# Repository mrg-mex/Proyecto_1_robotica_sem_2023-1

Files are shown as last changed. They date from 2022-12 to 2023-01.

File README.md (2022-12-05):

# Proyecto_1_robotica_sem_2023-1
## Implementación de un robot 5R, con motores de modelismo

## Participantes
- M.I. Erik Peña Medina (responsable)
- Castañeda López Josué Ángel (participante) 
- López Ortiz Alan (participante)
- Nava Dominguez José Carlos (participante)

## Objetivo

Implementar un robot un robot serial de cinco grados de libertad que conforme un banco de pruebas para prácticas de robótica, mediante el desarrollo de una interfase de control.

## Metas
- Desarrollar el modelo cinemático del robot serial de 5 grados de libertad en función del modelo de CAD que representa el robot físico. 
- Desarrollar el modelo URDF del robot para su implementación en Matlab y ROS2.
- Desarrollar una interfase de control de robot mediante una Raspberry Pi 4 y un controlador empleando Pca9685, empleando la librería de Adifrut en Python y ROS2.

## Productos
- Un repositorio con los archivos desarrollados durante el proyecto.
- Una interfase de control que permita programación de tareas mediante la planeación de tareas en el espacio de las juntas del robot.
- Completar el banco de pruebas físicos del robot de tal manera que pueda se implementada una interfaz de control en Matlab y ROS2.*

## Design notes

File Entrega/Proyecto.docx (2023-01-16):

Nombres: Castañeda López Josué Ángel, López Ortiz Alan & Nava Domínguez José Carlos Grupo: 01 Fecha: 13/01/2023

Proyecto: Implementación de un robot 5R, con motores de modelismo.

Objetivo

Implementar un robot serial de cinco grados de libertad que conforme un banco de pruebas para prácticas de robótica, mediante el desarrollo de una interfase de control.

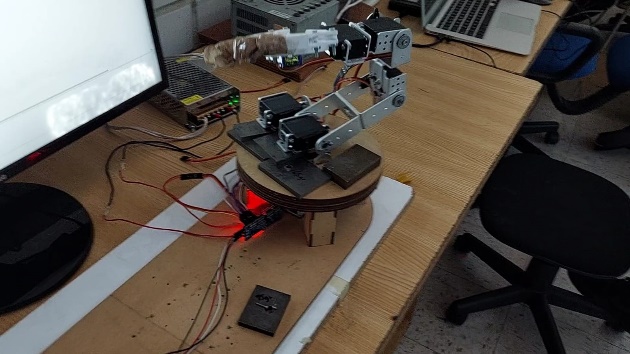
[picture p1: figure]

Figura 1: Robot 5R.

Configuración e instalación

Se nos proporcionó el robot de la figura 1, una raspberry Pi 4 computer model B, una pantalla y un mouse con teclado para poder realizar las actividades previstas del proyecto y el módulo PCA9685.

El profesor nos hizo el favor de instalar la imagen que contenía el sistema operativo Raspbian.

Como se decidió trabajar en Python necesitamos agregar soporte SMBus que incluye I2C. Con ayuda del siguiente código ingresado directo a la terminal se instaló el SMBus:

sudo apt-get install python-smbus<font></font>

sudo apt-get install i2c-tools

Con respecto a Python, utilizamos Thonny que ya venía instalado en el Raspbian.

Se conecto de primera instancia un Servomotor del robot modelo MG995 para empezar a hacer pruebas. Se conectó la Rasberry con el PCA9685 como se muestra en la siguiente figura:

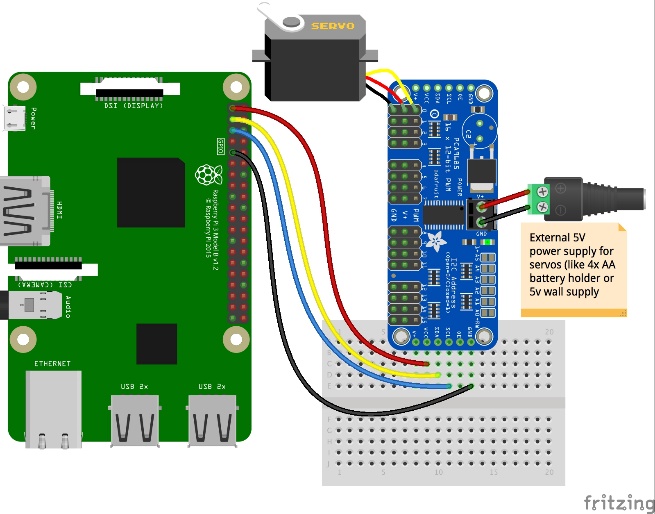
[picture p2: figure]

Figura 2: Conexión de un servomotor.

El PCA9685 funciona con el suministro de 3.3V por lo que debe de conectarse tal cual se ve en la imagen, esto para evitar estropear la RasPI.

Necesitamos instalar la librería Adafruit_Blinka para poder controlar los servomotores con Python, para esto se necesita ejecutar desde la terminal el siguiente comando:

sudo pip3 install adafruit-circuitpython-servokit

En este punto empezamos a realizar la primera prueba que puede verse en el siguiente código:

#Prueba 1 del servomotor 0 ubicado en el canal 0 con continuacion del servo 1 ubicado en el canal 1

import time

from adafruit_servokit import Servokit #en estas dos lineas importamos las librerias

#establecer canales respecto a la cantidad de canales del servo

#8 para servo FeatherWing de 8x12 bit PWM, 16 para Sheld/Hat/Bonnet

kit = Servokit(channels=16) #nuestro caso fue de 16

kit.servo[0].angle=180 #mover el servo conectado al canal 0 a 180 grados

kit.continuous_servo[1].throttle=1 #iniciar el servo de rotación continua conectado al canal 1 a toda velocidad hacia adelante

time.sleep(1) #tiempo de espera

kit.continuous_servo[1].throttle=-1 #iniciar el servo de rotación continua conectado al canal 1 a toda velocidad hacia atras

time.sleep(1)

kit.servo[0].angle=0 #mover el servo conectado al canal 0 a 0 grados

kit.continuous_servo[1].throttle=0 #detiene el servo de rotación continua conectado al canal 1

Una vez verificamos el funcionamiento del código, proseguimos a conectar todos los servos como se puede ver en la figura 3

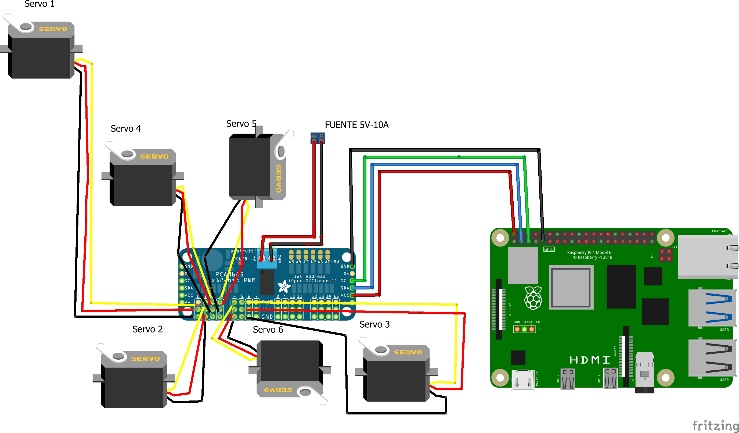
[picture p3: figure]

Figura 3: Conexión de los servomotores.

Continuamos con la prueba dos en la que movimos en conjunto todos los servos, también se hizo la prueba de moverlo uno a uno, pero finalmente se dejó como en el siguiente código:

#Prueba 2 conexion de todos los servomotores

import time

from adafruit_servokit import Servokit #en estas dos lineas importamos las librerias

#establecer canales respecto a la cantidad de canales del servo

#8 para servo FeatherWing de 8x12 bit PWM, 16 para Sheld/Hat/Bonnet

kit = Servokit(channels=16)

#servo1

kit.servo[0].angle=0 #mover el servo conectado al canal 0 a 0 grados

kit.continuous_servo[1].throttle=1 #iniciar el servo de rotación continua conectado al canal 1 a toda velocidad hacia adelante

time.sleep(1) #tiempo de espera

kit.continuous_servo[1].throttle=-1 #iniciar el servo de rotación continua conectado al canal 1 a toda velocidad hacia atras

time.sleep(1)

kit.servo[0].angle=0 #mover el servo conectado al canal 0 a 0 grados

kit.continuous_servo[1].throttle=0 #detiene el servo de rotación continua conectado al canal 1

#servo2

kit.servo[2].angle=0 #mover el servo conectado al canal 2 a 0 grados

kit.continuous_servo[1].throttle=1 #iniciar el servo de rotación continua conectado al canal 1 a toda velocidad hacia adelante

time.sleep(1) #tiempo de espera

kit.continuous_servo[1].throttle=-1 #iniciar el servo de rotación continua conectado al canal 1 a toda velocidad hacia atras

time.sleep(1)

kit.servo[2].angle=0 #mover el servo conectado al canal 2 a 0 grados

kit.continuous_servo[1].throttle=0 #detiene el servo de rotación continua conectado al canal 1

#servo4

kit.servo[3].angle=90 #mover el servo conectado al canal 3 a 90 grados

kit.continuous_servo[2].throttle=1 #iniciar el servo de rotación continua conectado al canal 2 a toda velocidad hacia adelante

time.sleep(1) #tiempo de espera

kit.continuous_servo[2].throttle=-1 #iniciar el servo de rotación continua conectado al canal 2 a toda velocidad hacia atras

time.sleep(1)

kit.servo[3].angle=0 #mover el servo conectado al canal 3 a 0 grados

kit.continuous_servo[2].throttle=0 #detiene el servo de rotación continua conectado al canal 2

#servo5

kit.servo[4].angle=90 #mover el servo conectado al canal 4 a 90 grados

kit.continuous_servo[3].throttle=1 #iniciar el servo de rotación continua conectado al canal 3 a toda velocidad hacia adelante

time.sleep(1) #tiempo de espera

kit.continuous_servo[3].throttle=-1 #iniciar el servo de rotación continua conectado al canal 3 a toda velocidad hacia atras

time.sleep(1)

kit.servo[4].angle=0 #mover el servo conectado al canal 4 a 0 grados

kit.continuous_servo[3].throttle=0 #detiene el servo de rotación continua conectado al canal 3

#servo6

kit.servo[5].angle=90 #mover el servo conectado al canal 5 a 90 grados

kit.continuous_servo[4].throttle=1 #iniciar el servo de rotación continua conectado al canal 4 a toda velocidad hacia adelante

time.sleep(1) #tiempo de espera

kit.continuous_servo[4].throttle=-1 #iniciar el servo de rotación continua conectado al canal 4 a toda velocidad hacia atras

time.sleep(1)

kit.servo[5].angle=0 #mover el servo conectado al canal 5 a 0 grados

kit.continuous_servo[4].throttle=0 #detiene el servo de rotación continua conectado al canal 4

Una vez verificamos el funcionamiento de los motores, nos percatamos que el robot estaba mal armado y la posición 0 de nuestros motores no correspondía con la posición 0 de las piezas, por lo que se prosiguió a corregir este error.

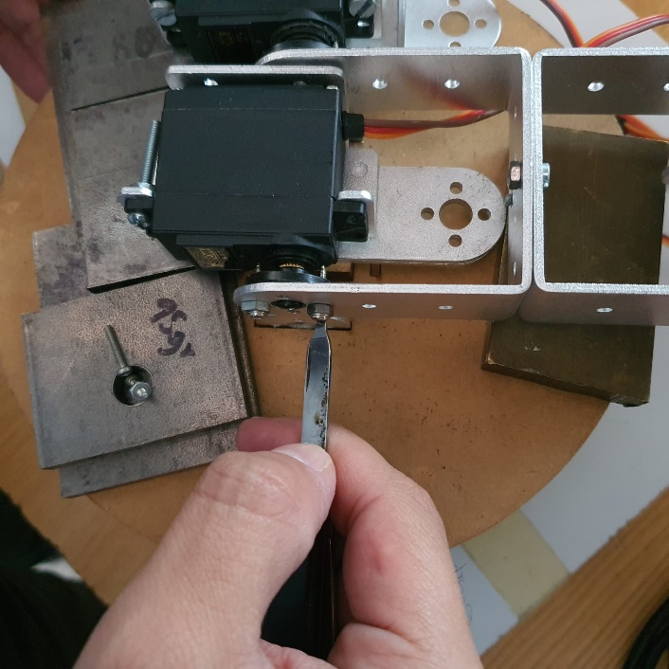
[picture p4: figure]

Figura 4: Corrección de las piezas del motor.

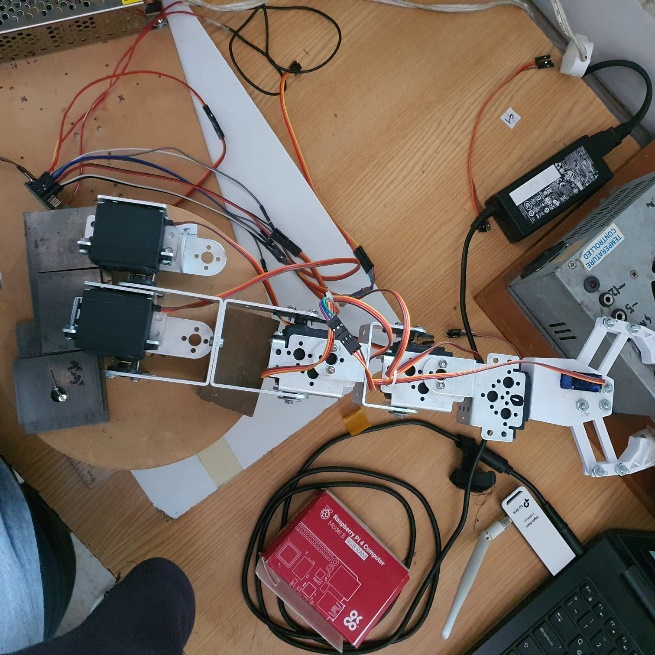
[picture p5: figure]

Figura 5: Robot en posición 0.

Continuamos con la prueba tres como en el siguiente código:

#Prueba 3 conexion de todos los servomotores sin retrocesos

from time import *

from adafruit_servokit import Servokit #en estas dos lineas importamos

#establecer canales respecto a la cantidad de canales del servo

#8 para servo FeatherWing de 8x12 bit PWM, 16 pata Sheld/Hat/Bonnet

kit = Servokit(channels=16)

#Se colocan los angulos iniciales de todos los servos

kit.servo[0].angle=0 #servo conectado al canal 0 a 0 grados

kit.servo[1].angle=0 #servo conectado al canal 1 a 0 grados

kit.servo[2].angle=0 #servo conectado al canal 2 a 0 grados

kit.servo[3].angle=0 #servo conectado al canal 3 a 0 grados

kit.servo[4].angle=0 #servo conectado al canal 4 a 0 grados

def servo1():

kit.servo[0].angle=0 #servo1 conectado en el canal 0 se posiciona a 0 grados

def servo2():

kit.servo[1].angle=90 #servo2 conectado en el canal 1 se posiciona a 90 grados

def servo4():

kit.servo[2].angle=0 #servo4 conectado en el canal 2 se posiciona a 0 grados

def servo5():

kit.servo[3].angle=0 #servo5 conectado en el canal 3 se posiciona a 0 grados

def servo6():

kit.servo[4].angle=0 #servo6 conectado en el canal 4 se posiciona a 0 grados

#Se crea un bucle

while True:

servo1()

sleep(0.5)

servo2()

sleep(0.5)

servo4()

sleep(0.5)

servo5()

sleep(0.5)

servo6()

sleep(0.5)

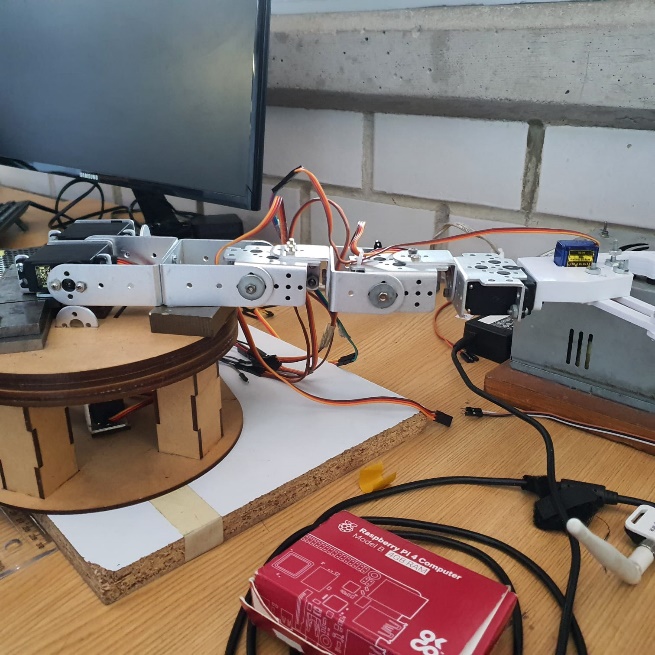
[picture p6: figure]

Figura 5: Robot en ejecución Prueba3.

Con la prueba 3 nos dimos cuenta de que la fuerza en el servomotor 2 no era suficiente para poner el robot en posición de 90°, algo que ya suponíamos porque las dimensiones y masa del robot suponen un para muy grande. Por este motivo y dando solución a este problema decidimos acoplar el motor 3 en paralelo al motor 2 y de esta forma poder soportar el par generado por el robot. Un problema que tuvimos con esto fue de nuevo ajustar a cero el servomotor 3 y, sobre todo, acoplarlo con el servomotor 2.

Después de volver a calibrar los motores se conecto el servomotor 3 como se puede apreciar en la figura 6 y se ejecutó el siguiente código:

#Prueba Final robot levantado a 90 grados

from time import *

from adafruit_servokit import Servokit #en estas dos lineas importamos

#establecer canales respecto a la cantidad de canales del servo

#8 para servo FeatherWing de 8x12 bit PWM, 16 pata Sheld/Hat/Bonnet

kit = Servokit(channels=16)

#Se colocan los angulos iniciales de todos los servos

kit.servo[0].angle=0 #servo conectado al canal 0 a 0 grados

kit.servo[1].angle=0 #servo conectado al canal 1 a 0 grados

kit.servo[2].angle=0 #servo conectado al canal 2 a 0 grados

kit.servo[3].angle=0 #servo conectado al canal 3 a 0 grados

kit.servo[4].angle=0 #servo conectado al canal 4 a 0 grados

kit.servo[5].angle=0 #servo conectado al canal 5 a 0 grados

def servo1():

kit.servo[0].angle=0 #servo1 conectado en el canal 0 se posiciona a 0 grados

def servo2():

kit.servo[1].angle=90 #servo2 conectado en el canal 1 se posiciona a 90 grados

def servo3():

kit.servo[5].angle=90 #servo5 conectado en el canal 1 se posiciona a 90 grados

def servo4():

kit.servo[2].angle=0 #servo4 conectado en el canal 2 se posiciona a 0 grados

def servo5():

kit.servo[3].angle=0 #servo5 conectado en el canal 3 se posiciona a 0 grados

def servo6():

kit.servo[4].angle=0 #servo6 conectado en el canal 4 se posiciona a 0 grados

#Se crea un bucle

while True:

servo1()

sleep(0.5)

servo2()

sleep(0.5)

servo3()

sleep(0.5)

servo4()

sleep(0.5)

servo5()

sleep(0.5)

servo6()

sleep(0.5)

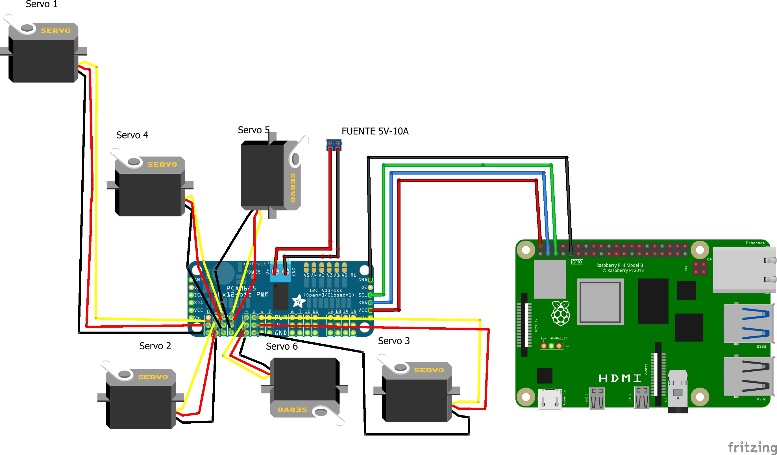
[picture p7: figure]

Figura 6: Conexión de los servomotores completa.

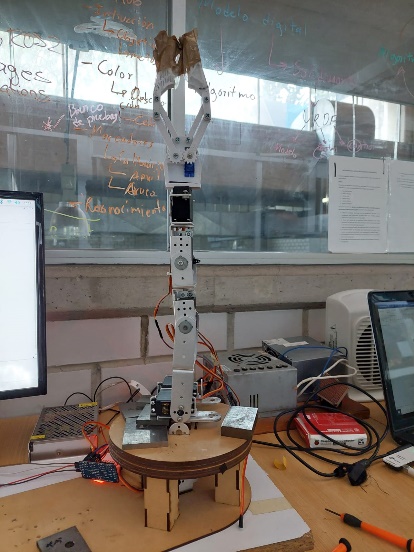
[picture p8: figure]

Figura 7:Robot levantado a 90°.

Referencias

Universidad Nacional Autónoma de México Facultad de Ingeniería Robótica

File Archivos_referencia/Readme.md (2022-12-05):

# Drive de referencia

https://drive.google.com/drive/folders/1qxG93VuVd_5UFDO-JclJPosKGj1U45Qc

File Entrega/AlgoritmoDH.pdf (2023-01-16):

Universidad Nacional Autónoma de México Facultad de Ingeniería
Robótica

Algoritmo Denavit-Hartenberg:

1. Colocar los ejes z0, z1,⋯zn−1
Colocar el eje zi−1 sobre el eje de giro de la articulación i, si es de revolución o sobre el eje de desplazamiento de la articulación i, si es prismática.

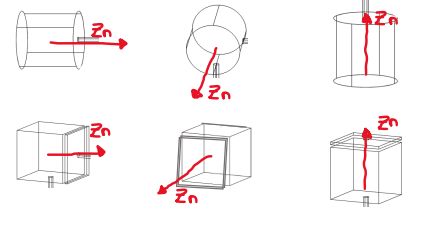
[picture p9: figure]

2. Completar el sistema de coordenadas de la base comenzando por o0 en un punto conveniente sobre el eje z0, colocar x0, y0 para formar un sistema ortonormal dextrógiro.
3. Colocar los orígenes o0, o1,⋯on−1 de acuerdo con los ejes zi−1& zi
- Si zi−1& zi

se interceptan, colocar oi en la intersección.
- Si zi−1& zi

son paralelos, colocar oi en cualquier lugar conveniente sobre zi
- Si zi−1& zi no son paralelos ni se interceptan, colocar oi en la intersección de zi con la normal común de zi−1& zi .
4. Colocar los ejes x0, x1,⋯xn−1 de acuerdo con los ejes zi−1& zi
- Si zi−1& zi

se interceptan, colocar xi en la normal al plano que forman zi−1& zi pasando en oi
- Si zi−1& zi no se interceptan, colocar xi en la normal común a zi−1& zi pasando en oi
5. Colocar los ejes y0, y1,⋯yn−1 completando los sistemas de coordenadas.
6. Colocar el sistema de coordenadas del efector final, colocar on en el punto más importante, luego colocar el eje zn paralelo a zn−1 y pasando por on.
Colocar el eje xn de tal forma que se intersecte a

zn−1.
Completar el sistema de coordenadas para formar un sistema dextrógiro.

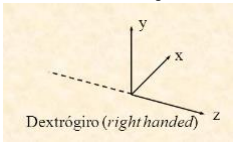
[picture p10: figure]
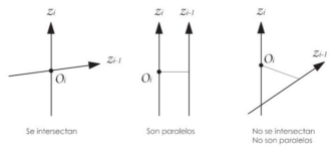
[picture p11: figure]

Universidad Nacional Autónoma de México Facultad de Ingeniería
Robótica
7. Formar la tabla de parámetros
i | ai | di | αi | θi
1…
…n
- ai es la distancia desde la intersección de los ejes zi−1& xi hasta el origen oi
Es la distancia medida a lo largo del eje xi a zi−1.
- di es la distancia desde el origen oi−1 hasta la intersección de los ejes zi−1& xi .
Es la distancia medida a lo largo del eje

zi−1 a xi
Si la articulación i es prismática, este parámetro es variable y se denotara como di
- αi es el ángulo entre zi−1 hasta zi tomando a xi como eje de giro.
- | θi | es el ángulo desde el eje
xi−1 | hasta | el | eje
xi

tomando a zi−1 como eje de giro. Si la articulación i es de revolución, este parámetro es variable y se denota como θi

8. Formar las n transformaciones homogéneas de acuerdo con la siguiente plantilla.

1

Cos | Sin Cos | Sin Sin | Cos
Sin | Cos Cos | Cos Sin | Sin
()
0 | Sin | Cos
0 | 0 | 0 | 1
i | i | i | i | i | i | i
i | i | i | i | i | i | i | i
i | i
i | i | i

a
a
Hq
d
θ | θ | α | θ | α | θ
θ | θ | α | θ | α | θ
α | α

−

é | ù −
ê | ú −
= ê | | ú
ê | | ú
ê | ú ë | û

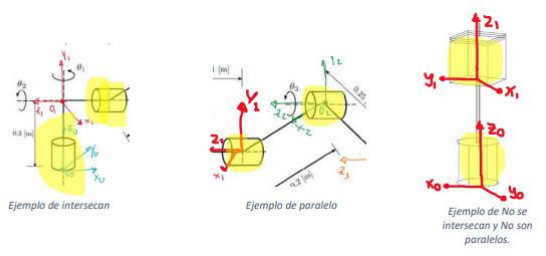
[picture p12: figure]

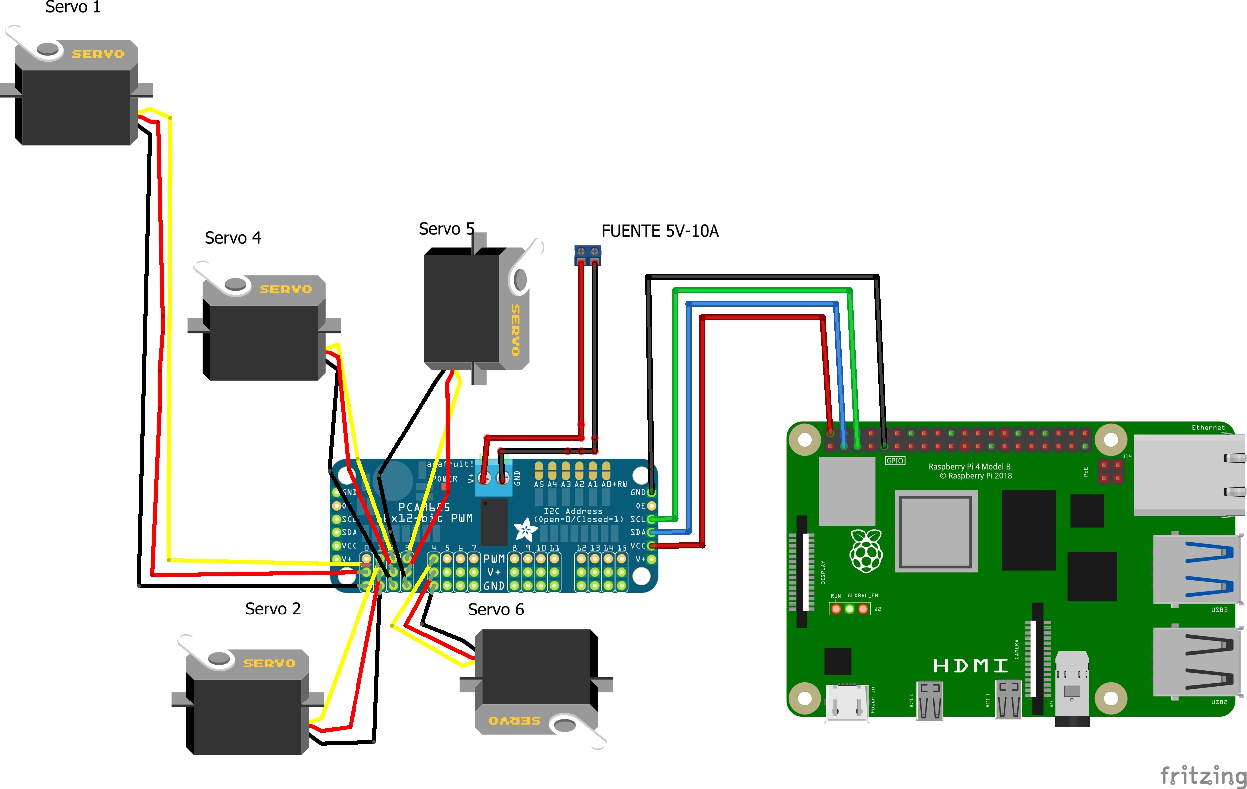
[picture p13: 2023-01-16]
Entrega/ConexionServomotoresPreliminar.jpg

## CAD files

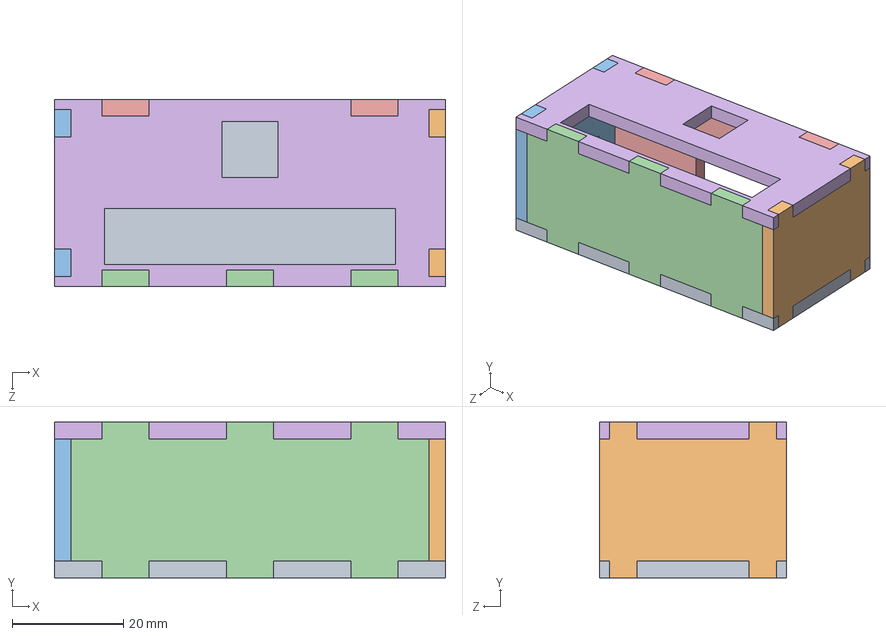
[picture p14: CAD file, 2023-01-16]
Entrega/Case PCA Final/Ensamble_Case_PCA.SLDASM
70.2 x 28.0 x 33.7 mm
BasePCA
LateralIzqPCA
LateralDerPCA
LateraAntPCA
LateralPostPCA
TapaPCA

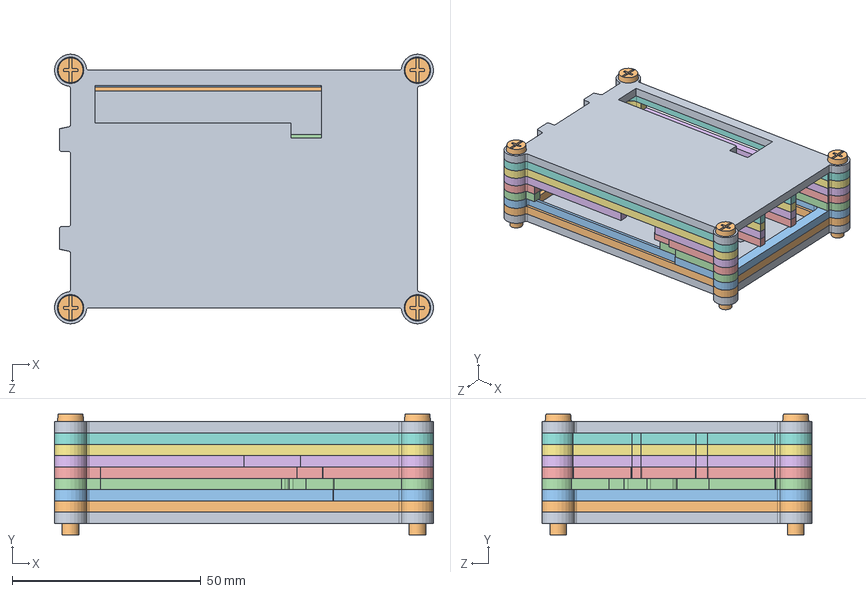
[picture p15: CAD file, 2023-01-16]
Entrega/Case Raspberry Final/CASE Assembly.SLDASM
100.5 x 32.0 x 71.5 mm
pt4
Pt6
Pt7
Pt8
Pt9
screw x 4

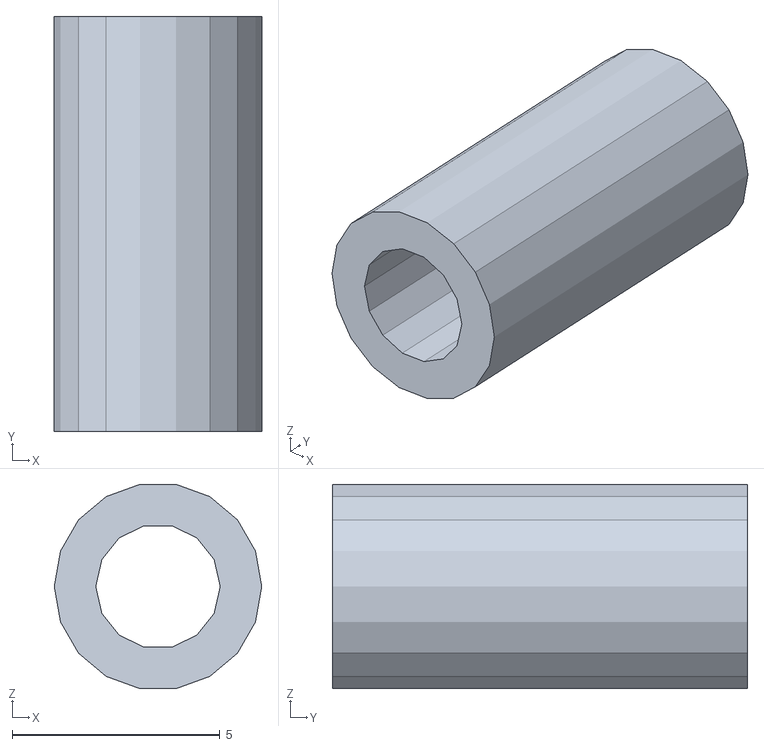
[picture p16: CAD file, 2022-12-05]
Archivos_referencia/spacer_long.stl
5.00 x 10.0 x 4.92

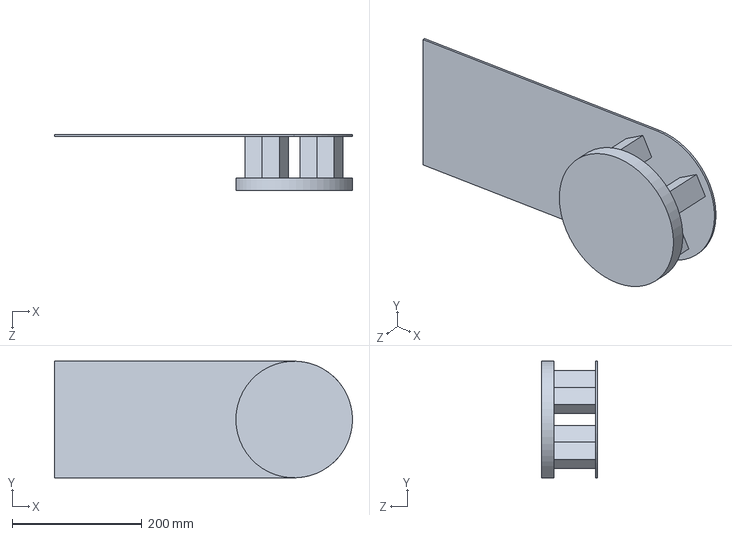
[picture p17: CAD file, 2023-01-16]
Entrega/BaseRobot.SLDPRT
460.0 x 180.0 x 86.0 mm

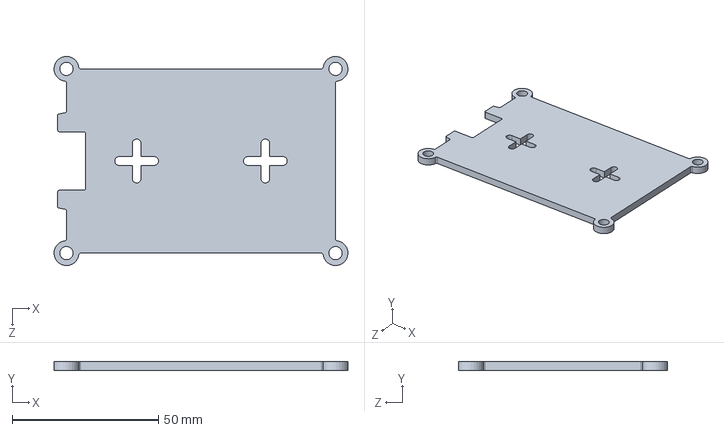
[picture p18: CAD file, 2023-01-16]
Entrega/Case Raspberry Final/Part 1.SLDPRT
100.5 x 3.00 x 71.5 mm

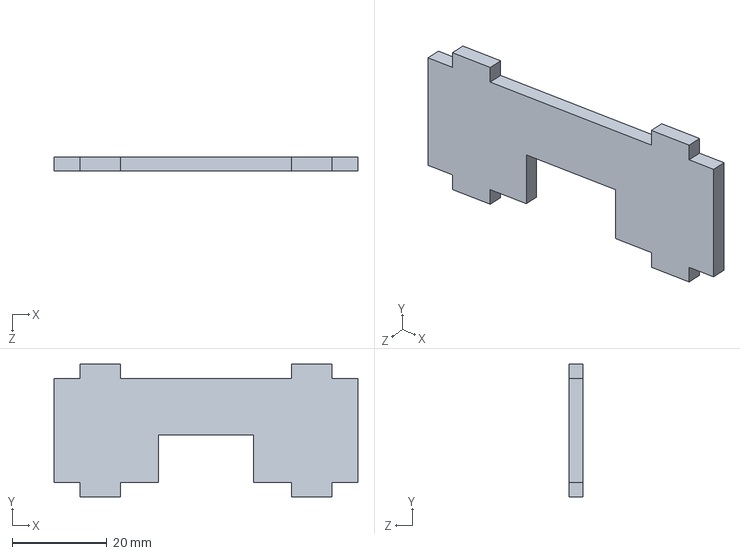
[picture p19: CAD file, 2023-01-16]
Entrega/Case PCA Final/LateralPostPCA.SLDPRT
64.2 x 28.0 x 3.00 mm

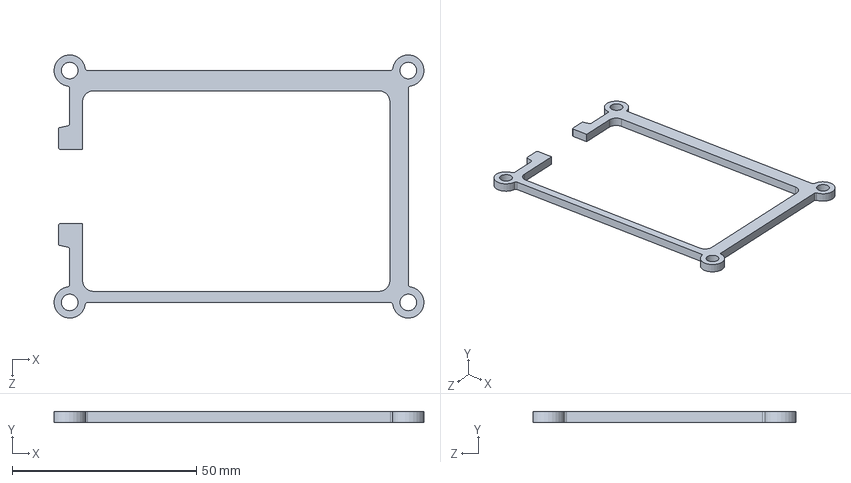
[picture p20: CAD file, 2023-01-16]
Entrega/Case Raspberry Final/Part2.SLDPRT
100.5 x 3.00 x 71.5 mm

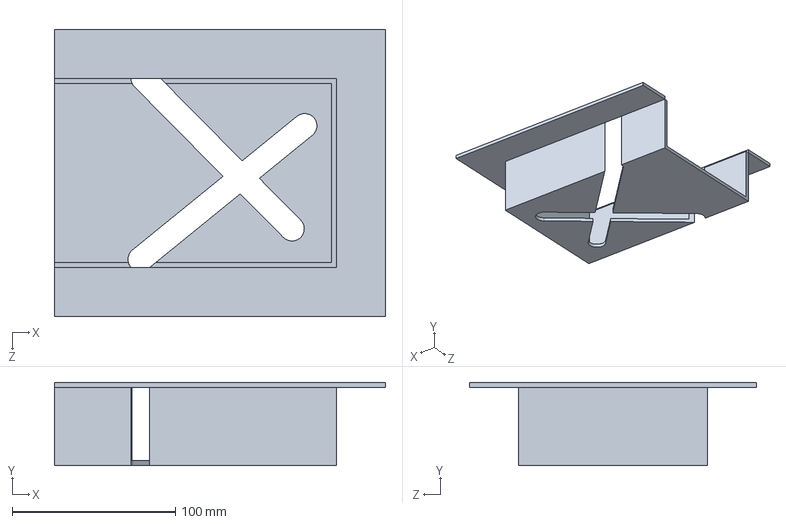
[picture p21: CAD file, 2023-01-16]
Entrega/CaseFuente.SLDPRT
203.0 x 51.0 x 176.0 mm

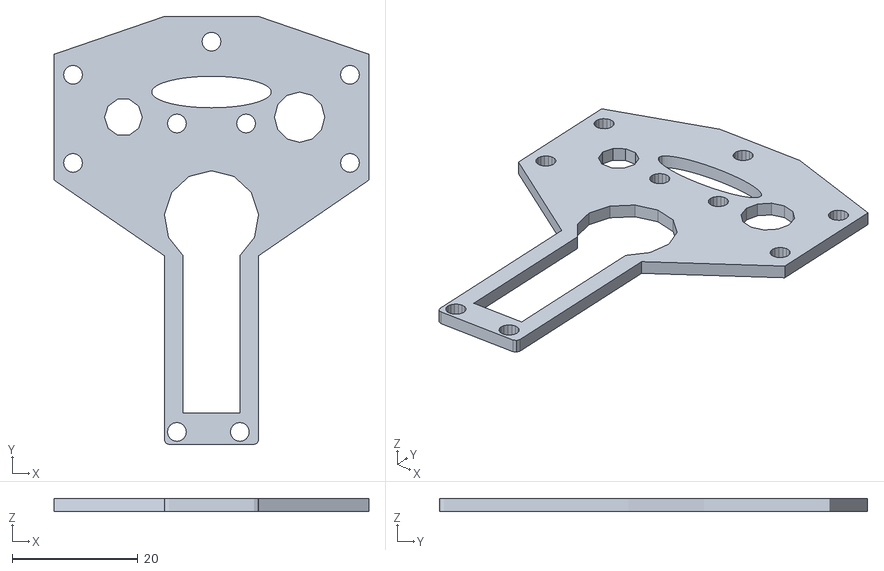
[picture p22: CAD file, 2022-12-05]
Archivos_referencia/gripper_palm.stl
50.0 x 68.0 x 2.00

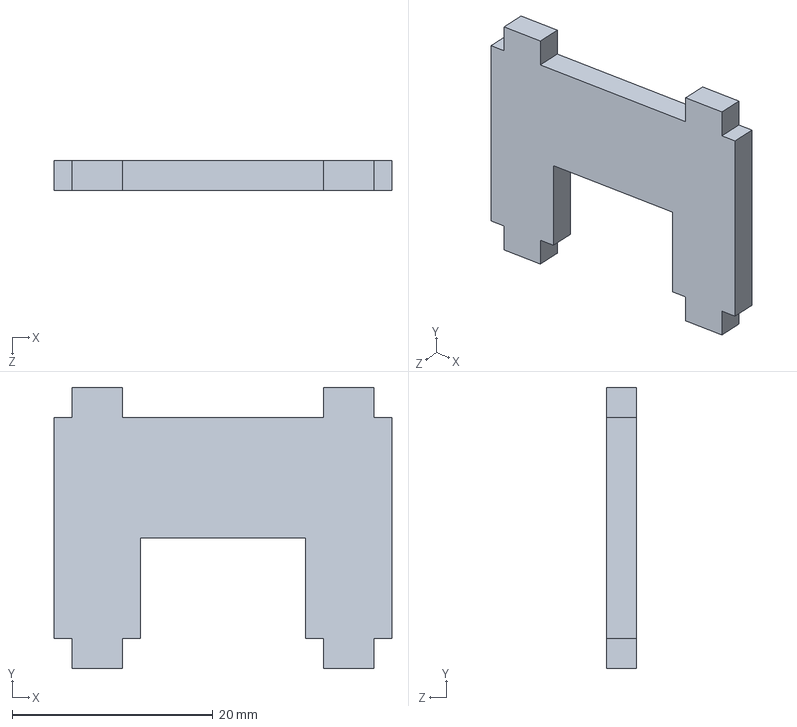
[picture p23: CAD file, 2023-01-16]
Entrega/Case PCA Final/LateralDerPCA.SLDPRT
33.7 x 28.0 x 3.00 mm

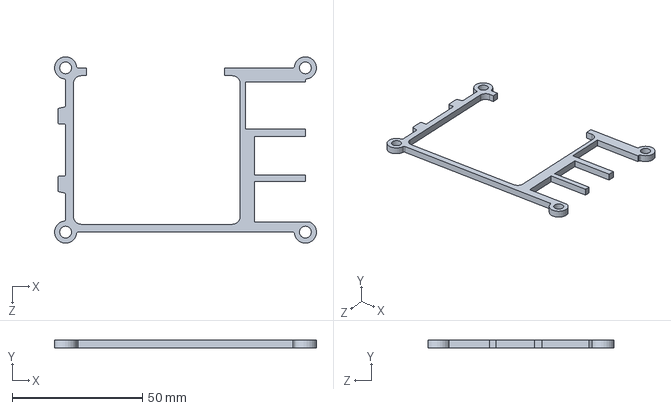
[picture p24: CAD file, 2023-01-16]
Entrega/Case Raspberry Final/Pt7.SLDPRT
100.5 x 3.00 x 71.5 mm

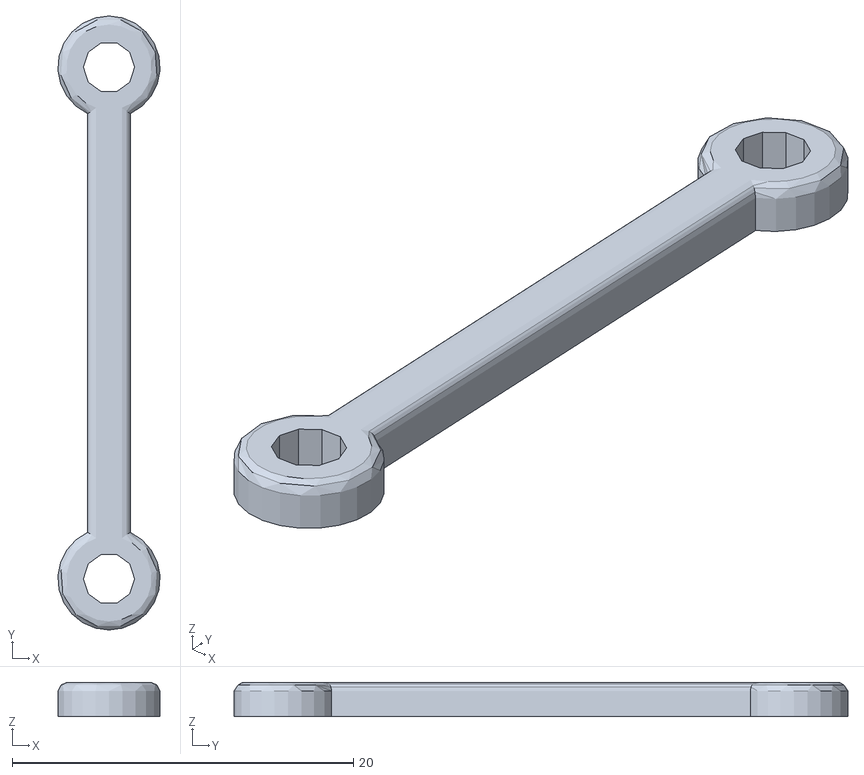
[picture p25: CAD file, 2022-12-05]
Archivos_referencia/gripper_palm_to_finger_small.stl
5.99 x 36.0 x 2.00

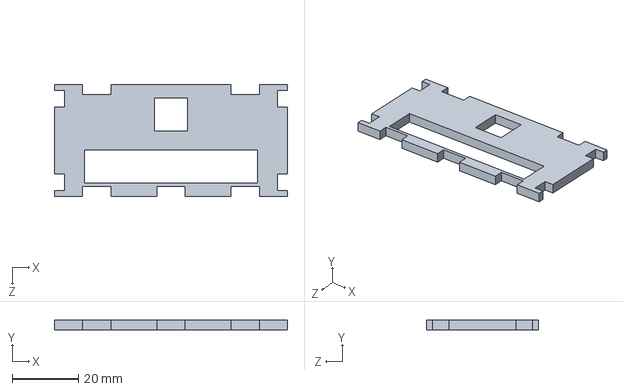
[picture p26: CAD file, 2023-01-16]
Entrega/Case PCA Final/TapaPCA.SLDPRT
70.2 x 3.00 x 33.7 mm

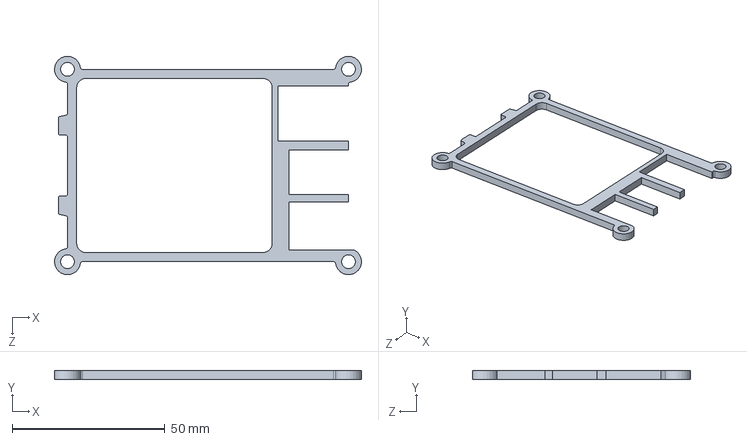
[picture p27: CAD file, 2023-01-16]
Entrega/Case Raspberry Final/Pt8.SLDPRT
100.5 x 3.00 x 71.5 mm

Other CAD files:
Archivos_referencia/gripper_palm_to_finger_large_lo.stl
Entrega/Case PCA Final/BasePCA.SLDPRT
Entrega/Case Raspberry Final/pt4.SLDPRT
Archivos_referencia/gripper_palm_to_finger_large.stl
Archivos_referencia/aluminum_servo_horn.stl
Archivos_referencia/finger.stl
Archivos_referencia/gripper_l_bracket.stl
Archivos_referencia/l_type_servo_bracket.stl
Archivos_referencia/long_u_type_servo_bracket.stl
Archivos_referencia/m3_nut.stl
Archivos_referencia/m3_nut__temp.stl
Archivos_referencia/mg996r_servo.stl
Archivos_referencia/miniature_ball_radial_bearing.stl
Archivos_referencia/round_head_m3_10_screw.stl
Archivos_referencia/round_head_m3_14_screw.stl
Archivos_referencia/round_head_m3_4_screw.stl
Archivos_referencia/round_head_m3_6_screw.stl
Archivos_referencia/round_head_m3_8_screw.stl
Archivos_referencia/spacer_short.stl
Archivos_referencia/u_type_robot_waist_bracket.stl
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

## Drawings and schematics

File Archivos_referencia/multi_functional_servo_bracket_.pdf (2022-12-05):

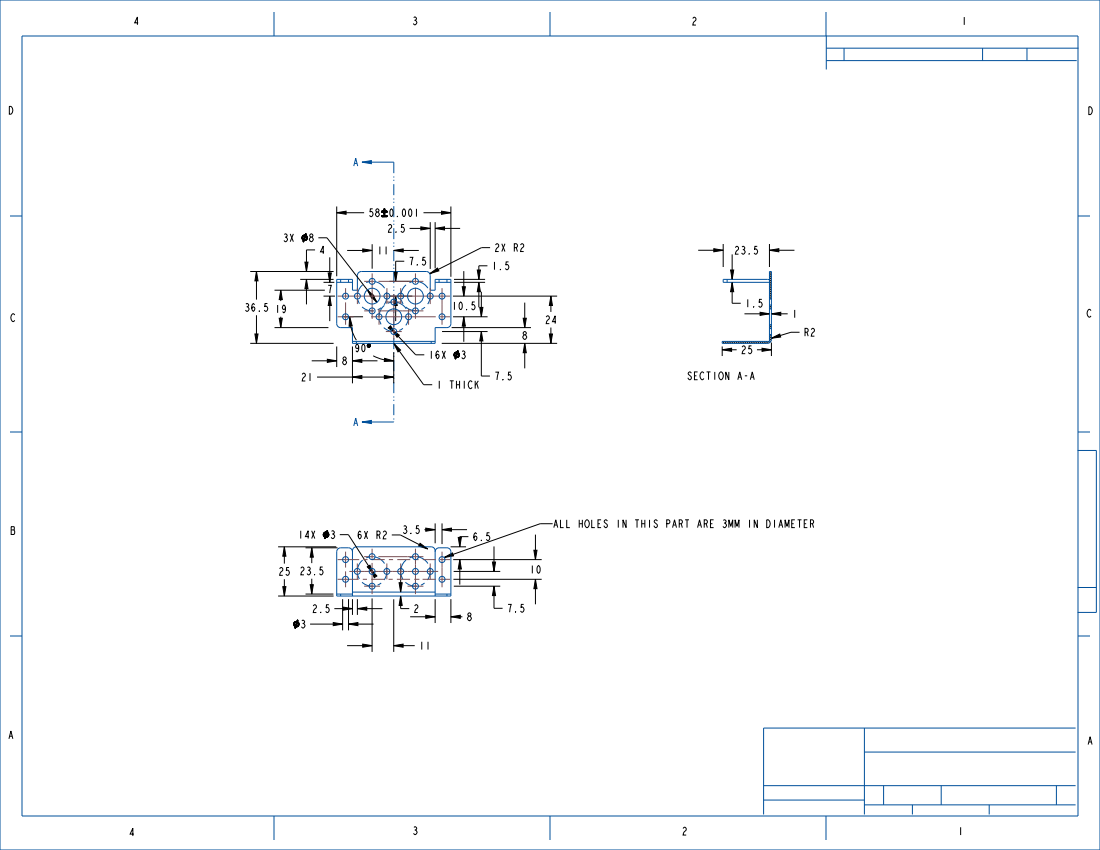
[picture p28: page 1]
1 THICK; ALL HOLES IN THIS PART; ARE 3MM IN DIAMETER; SECTION A-A

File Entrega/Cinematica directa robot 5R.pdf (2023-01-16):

# CinemáticaÊDirectaÊdeÊunÊrobotÊ5R

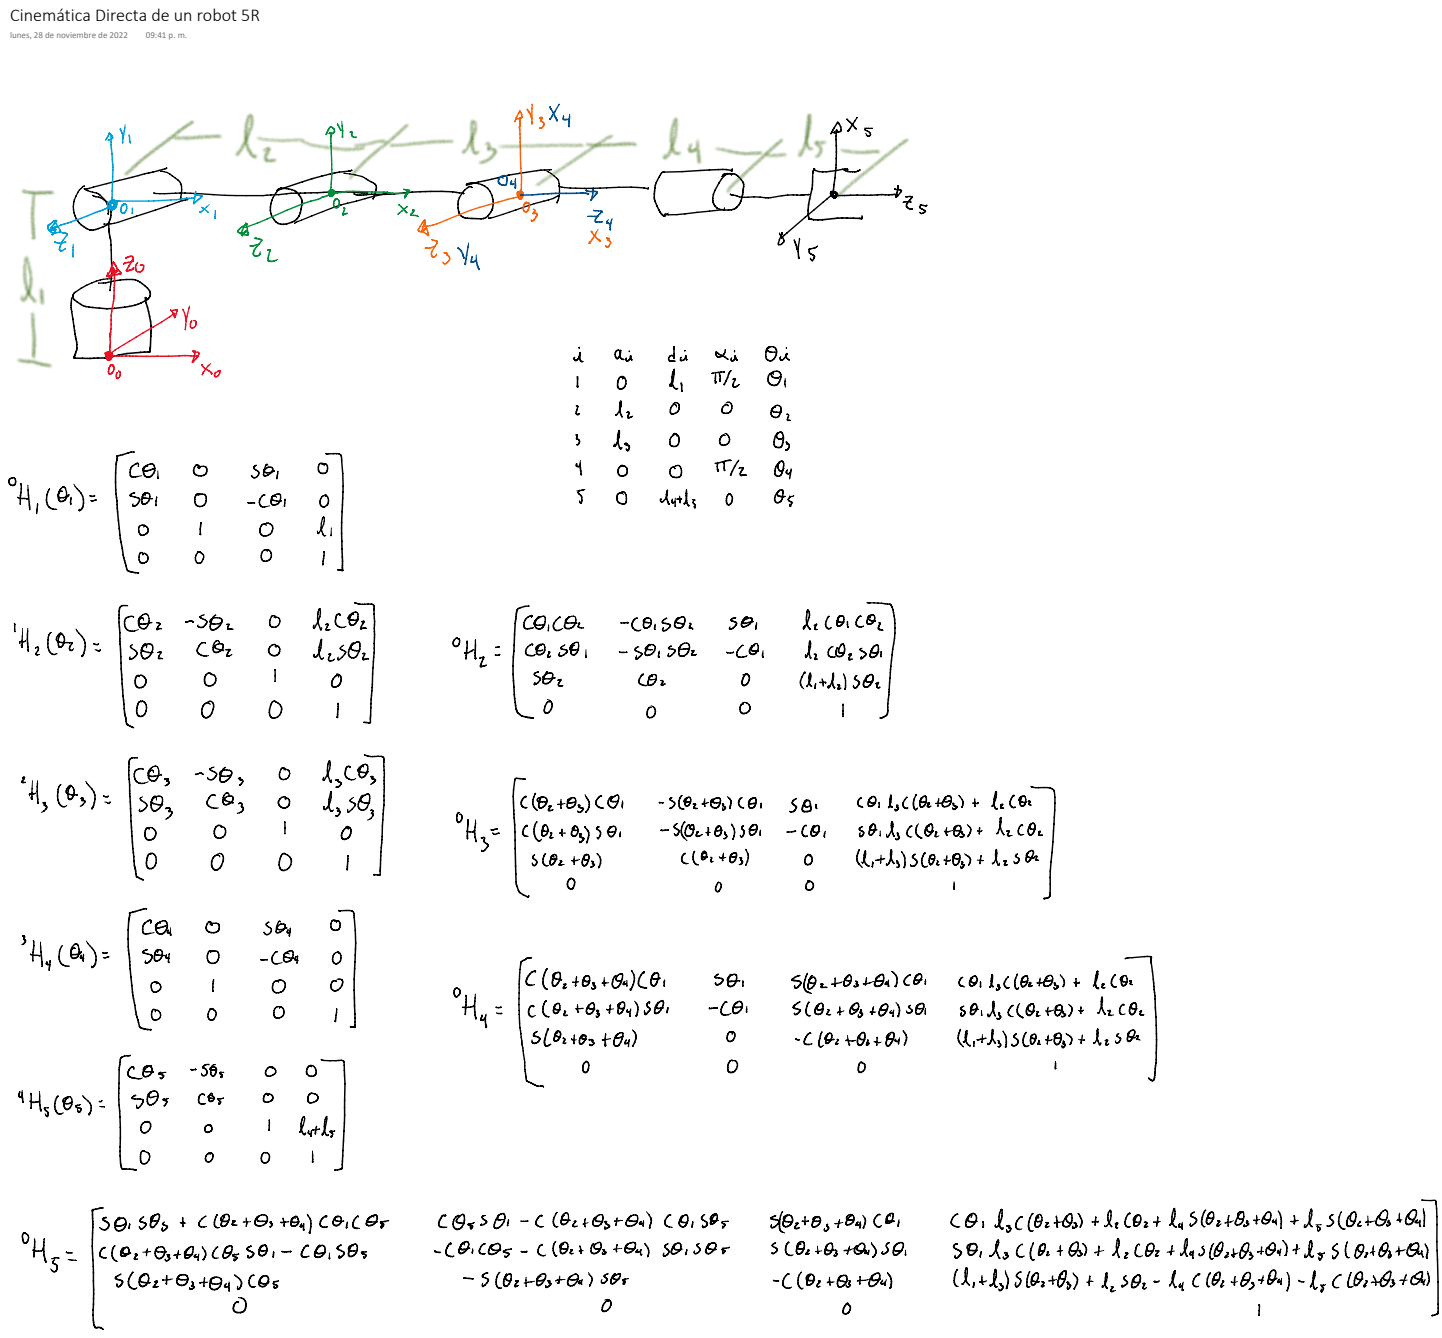
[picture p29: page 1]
lunes, 28 de noviembre de 2022

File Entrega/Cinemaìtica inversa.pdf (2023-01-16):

# Cinemática inversa

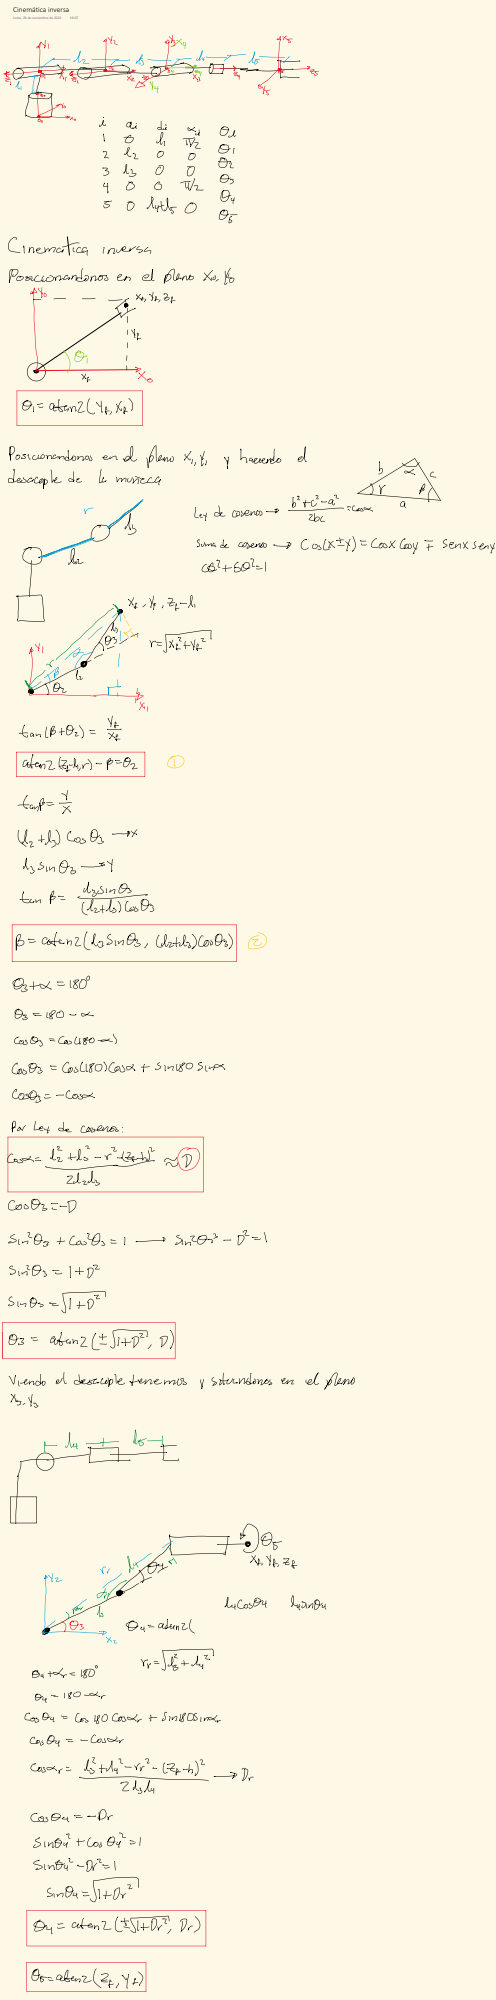
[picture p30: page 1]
lunes, 28 de noviembre de 2022

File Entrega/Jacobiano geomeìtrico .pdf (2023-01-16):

# Jacobiano geométrico

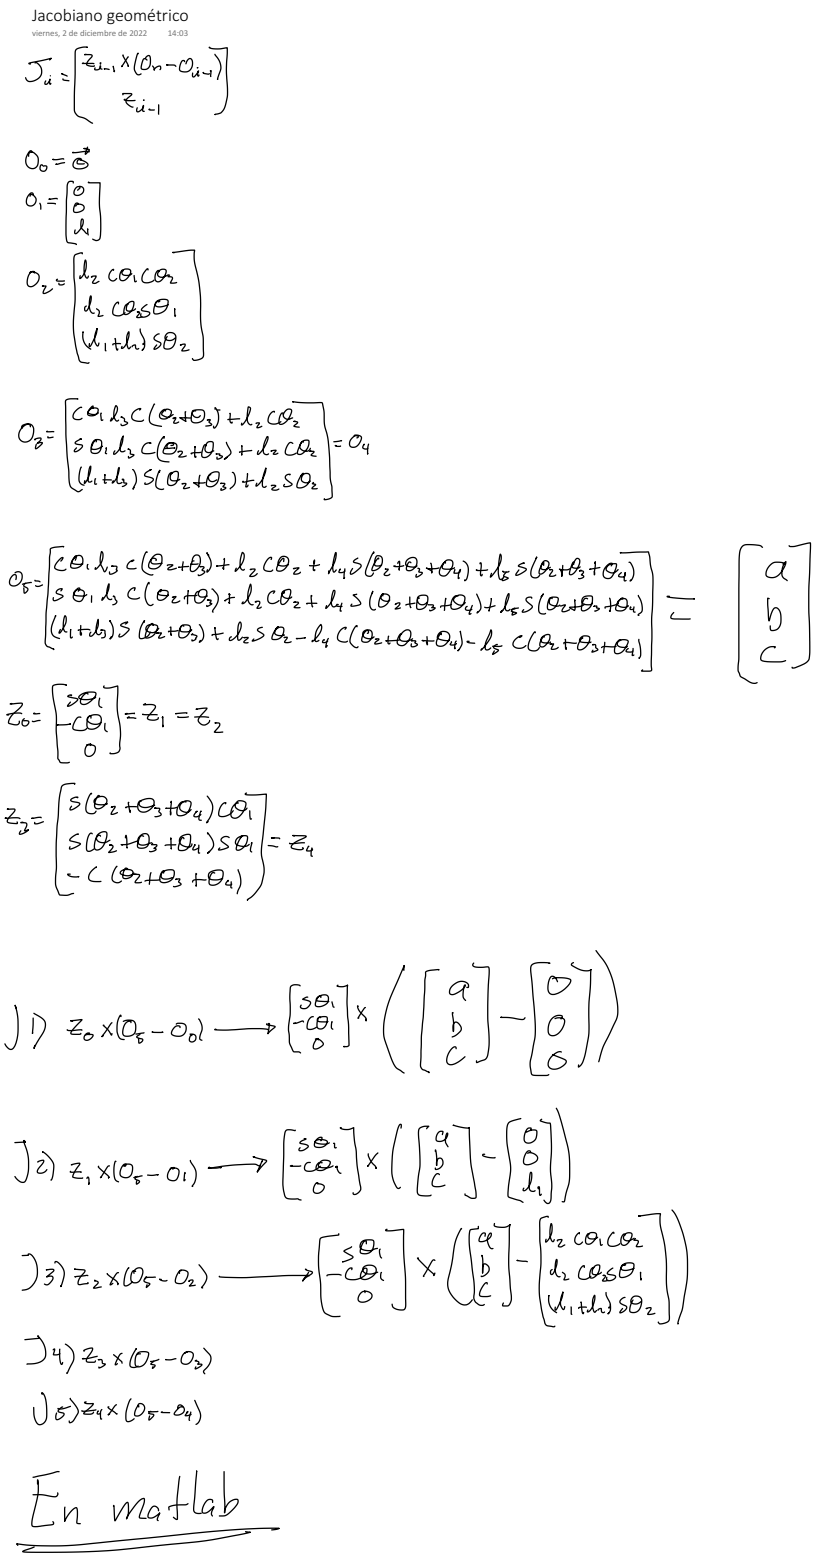
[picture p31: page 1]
viernes, 2 de diciembre de 2022

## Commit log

2022-12-03 Primer Commit
    definición de la portada del proyecto.
2022-12-05 Commit Archivos de referencia STL
    Archivos para ensamblar al robot
2022-12-05 Archivos stl
    Archivos stl de los brackets, falta la base y su conversion y ensamble para generar el modelo y el URDF
    [aluminum_servo_horn.stl, finger.stl, gripper_l_bracket.stl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]
